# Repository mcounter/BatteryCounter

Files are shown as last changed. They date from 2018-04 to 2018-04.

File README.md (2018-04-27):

# **Battery Counter**

A fully autonomous counter of visitors - **MCounter attom**.

This small device can work approximately 1 year with just 2 *LiSOCl2* AA batteries. And it can be assembled manually in small lab without expensive equipment and components used. All parts of this device was designed by me. Main purpose why I share this project - it's demonstration of my skills (part of my portfolio). Fill free use it under [GNU GPL v3](./LICENSE) license terms.

I have no much time to provide good documentation for this projects. But I believe it's well-structured even for people with minimal experience in Embedded Devices. PCB layouts includes mechanical layers which can be visualized in 3D to easy understand location of all components and it physical sizes.

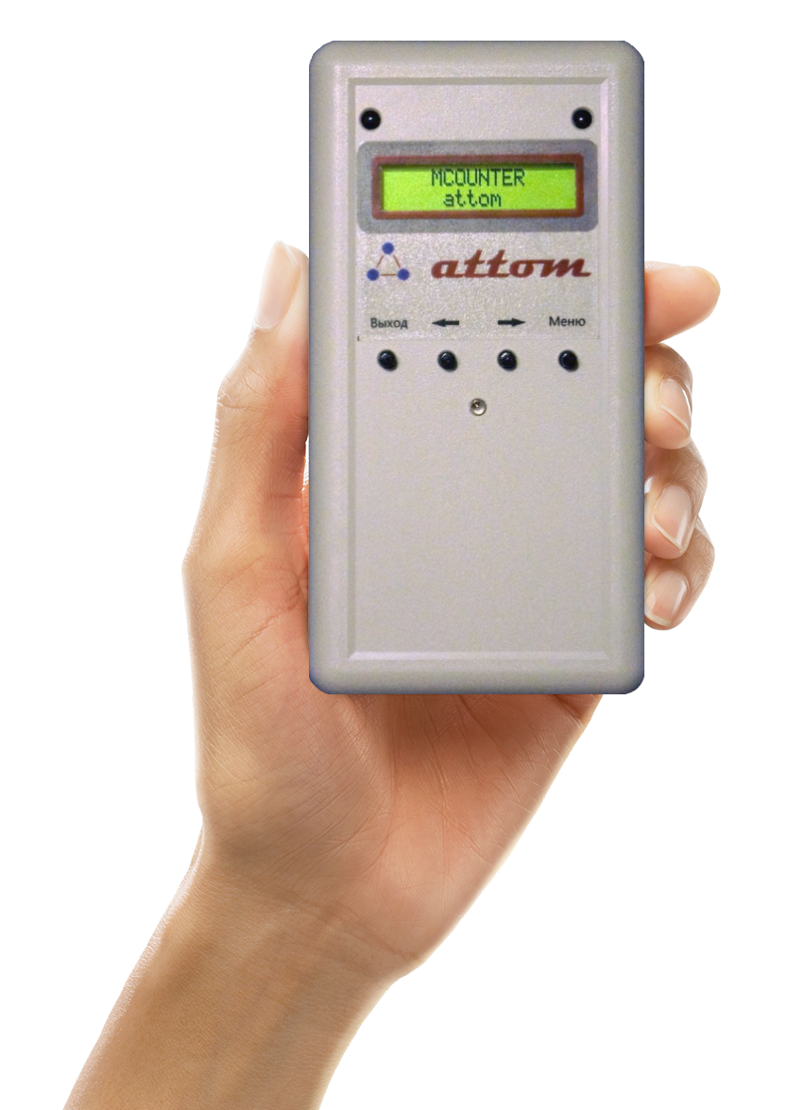
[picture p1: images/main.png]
Battery Counter


*The photo of the real prototype of the device receiver, manually assembled by me. Hand on the background is not mine :)*

**Brief description**

The device is used for automatic counting of people in shopping centers. It consists of 2 parts: Transmitter and Receiver. Device contains small LED digital display with backlight and keyboard with 4 keys. Principle of work: IR (infra-red) rays emitted by Transmitter can be interrupted by passed human. These short termination of IR rays are detected by Receiver and recorded in internal memory, aggregated by hours, days, weeks, months and displayed in the form of different reports on the small device display. Device has good system of noise suppression and can work in different environments and under different conditions.

* Hardware part is designed in the Altium Designer 14.3.10 - [www.altium.com](https://www.altium.com/)
* Software part is designed in the IAR Embedded Workbench for AVR V6.12.1 - [www.iar.com](https://www.iar.com/)
* Menu Builder was designed on C# .NET in VS 2012.
* Receiver microcontroller - **Atmega328P**
* Transmitter microcontroller - **Atmega48PA**
* User documentation (in Russian) - [mcounter_attom_user_guide.pdf](https://mcounter.com.ua/filesdocs/mcounterx/mcounter_attom_user_guide.pdf)

**Project content**
* [micro](./micro) - folder with source code for device Receiver and Transmitter parts.
* [micro/BattRX](./micro/BattRX) - Receiver project.
* [micro/BattTX](./micro/BattTX) - Transmitter project.
* [schemas](./schemas) - folder with component library, board rules and PCB layouts designed in Altium Designer.
* [schemas/Common/Rules](./schemas/Common/Rules) - board rules for Altium Designer.
* [schemas/Common/Library](./schemas/Common/Library) - component library for Altium Designer.
* [schemas/BatteryCounter](./schemas/BatteryCounter) - PCB layouts for Receiver and Transmitter parts.
* [other/LCDMenuBuilder](./other/LCDMenuBuilder) - menu builder - C# .NET program to design and build device menu, use it to translate menu. Program converts menu in set of UserInterface* header and cpp files. Specify target path to [micro/BattRX](./micro/BattRX) and files will be automatically added in the project.
* [LICENSE](./LICENSE) - GNU GENERAL PUBLIC LICENSE v3.

*Thank you for your interest!*

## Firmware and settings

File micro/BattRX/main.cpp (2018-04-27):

#ifndef _MAIN_CPP_
#define _MAIN_CPP_

#include "GlobalSpace.h"
#include "DeviceManager.h"

void Initialization()
{
  __disable_interrupt();

  //Swith off analog comparator
  ACSR=(1<<ACD);  //Analog Comparator: Off

  //__watchdog_reset();
  //WDTCSR = (1<<WDCE) | (1<<WDE);
  //WDTCSR = (1<<WDP3) | (1<<WDE);

  //Enable pullup on all ports

  DDRB = 0x00;
  PORTB = 0xFF ^ ((1<<MEM_SS_BIT) | (1<<SPI_MOSI_BIT) | (1<<SPI_MISO_BIT) | (1<<SPI_SCK_BIT) | (1<<LCD_BACKLIGHT_BIT));
  DDRB = ((1<<MEM_SS_BIT) | (1<<SPI_MOSI_BIT) | (1<<SPI_MISO_BIT) | (1<<SPI_SCK_BIT) | (1<<LCD_BACKLIGHT_BIT));

  DDRC = 0x00;
  PORTC = 0xFF ^ ((1<<LCD_VDD_BIT) | (1<<INDICATOR_LED_BIT) | (1<<LCD_SDA_BIT) | (1<<LCD_SCL_BIT) | (1<<PHOTO1_VDD_BIT) | (1<<PHOTO2_VDD_BIT));
  DDRC = ((1<<LCD_VDD_BIT) | (1<<INDICATOR_LED_BIT) | (1<<LCD_SDA_BIT) | (1<<LCD_SCL_BIT) | (1<<PHOTO1_VDD_BIT) | (1<<PHOTO2_VDD_BIT));

  DDRD = 0x00;
  PORTD = 0xFF ^ ((1<<PHOTO1_IN_BIT) | (1<<PHOTO2_IN_BIT));
  DDRD = ((1<<PHOTO1_IN_BIT) | (1<<PHOTO2_IN_BIT));

  //Disable all external interrupts
  EIMSK = 0x00;

  //Disable all timer interrupts
  TIMSK0 = 0x00;
  TIMSK1 = 0x00;
  TIMSK2 = 0x00;

  //Disable unused modules
  PRR = (1<<PRTWI) | /*(1<<PRTIM0) |*/ (1<<PRTIM1) |                    //Disable TWI, Timer0, Timer1,
        /*(1<<PRTIM2) |*/ (1<<PRSPI) | (1<<PRUSART0) | (1<<PRADC);  //Timer2, SPI, USART0, ADC

  SMCR = 0x00; //Sleep Mode = Idle

  DeviceManager::init();

  __enable_interrupt();
}

int main()
{
  Initialization();

  DeviceManager::run();
}

#endif

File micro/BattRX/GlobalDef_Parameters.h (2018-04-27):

#ifndef __GLOBALDEF_PARAMETERS_H_
#define __GLOBALDEF_PARAMETERS_H_

#define clockFrequency                    (128000)
#define timerDiscreteness                 (5)
#define TWIClockFrequency                 (2560)

#define EXT_MEMORY_SIZE_HOUR_SEGMENT      (12288)
#define EXT_MEMORY_SIZE_DAY_SEGMENT       (3584)
#define EXT_MEMORY_SIZE_MONTH_SEGMENT     (512)
#define EXT_MEMORY_SIZE_TOTAL             (16384)
#define EXT_MEMORY_SEGMENTSIZE            (16)

#if (EXT_MEMORY_SIZE_HOUR_SEGMENT+EXT_MEMORY_SIZE_DAY_SEGMENT+EXT_MEMORY_SIZE_MONTH_SEGMENT > EXT_MEMORY_SIZE_TOTAL)
#error Incorrect memory size
#endif

#define COMMBUFFERSIZE_TWI_MASTER         (64)
#define COMMBUFFERSIZE_SPI_MASTER         (32)

#define LCD_DISPLAY_HEIGHT                (2)
#define LCD_DISPLAY_WIDTH                 (16)

#define DEVICE_PASSWORD_LENGTH            (8)
#define COUNTER_BODY_DETECTION_ADD_MS     (30)

#define BATTERY_CONFIGURATION_LI          (0)
#define BATTERY_CONFIGURATION_STD         (1)

#define BATTERY_CONFIGURATION_SELECTED    (BATTERY_CONFIGURATION_LI)

#endif

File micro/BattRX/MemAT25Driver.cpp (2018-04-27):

#ifndef __MEMAT25DRIVER_CPP_
#define __MEMAT25DRIVER_CPP_

#include <string.h>
#include "MemAT25Driver.h"
#include "CommProtocol_SPI_Master.h"
#include "MultyThreading.h"
#include "CommonFunctions.h"
#include "CRC8.h"

#define MEMAT25_VALPERSEGMENT_HOUR    (3)
#define MEMAT25_VALPERSEGMENT_DAY     (2)
#define MEMAT25_VALPERSEGMENT_MONTH   (2)

#define MEMAT25_ERRORIDLETIME   (3000)
#define MEMAT25_BLOCKTIME       (30000)

#define MEMAT25CMD_WREN         (0x06)
#define MEMAT25CMD_WRDI         (0x04)
#define MEMAT25CMD_RDSR         (0x05)
#define MEMAT25CMD_WRSR         (0x01)
#define MEMAT25CMD_READ         (0x03)
#define MEMAT25CMD_WRITE        (0x02)

#define MEMAT25STATUS_NORMAL    (0x02)
#define MEMAT25STATUS_FLG_BUSY  (0x01)

using namespace Functions::Common;

namespace MemAT25Driver
{
  typedef enum
  {
    MemAT25ResourceStatus_Disabled = 0x00,
    MemAT25ResourceStatus_Ready = 0x01,
    MemAT25ResourceStatus_Scheduled = 0x02,
    MemAT25ResourceStatus_InProcess = 0x03,
    MemAT25ResourceStatus_Blocked = 0x04,
  } TMemAT25ResourceStatus;

  typedef enum
  {
    MemAT25ProtocolStatus_WriteStatusRegWREN = 0,
    MemAT25ProtocolStatus_WriteStatusReg = 1,
    MemAT25ProtocolStatus_WriteDataWREN = 2,
    MemAT25ProtocolStatus_WriteData = 3,
    MemAT25ProtocolStatus_ReadData = 4,
    MemAT25ProtocolStatus_ParseData = 5,
    MemAT25ProtocolStatus_ReadDataValidate = 6,
    MemAT25ProtocolStatus_ValidateData = 7,
  } TMemAT25ProtocolStatus;

  typedef enum
  {
    MemAT25WaitingStatus_None = 0,
    MemAT25WaitingStatus_Schedule = 1,
    MemAT25WaitingStatus_Wait = 2,
  } TMemAT25WaitingStatus;

  typedef struct
  {
    unsigned char data[12];

    unsigned long periodNum:24;
    unsigned long crc8:8;
  } TMem25DataSegmentStd;

  typedef struct
  {
    unsigned long InCnt1:13;
    unsigned long OutCnt1:13;
    unsigned long NoSensorMin1:6;

    unsigned long InCnt2:13;
    unsigned long OutCnt2:13;
    unsigned long NoSensorMin2:6;

    unsigned long InCnt3:13;
    unsigned long OutCnt3:13;
    unsigned long NoSensorMin3:6;

  } TMem25DataSegmentHour;

  typedef struct
  {
    unsigned short InCnt1;
    unsigned short OutCnt1;
    unsigned short NoSensorMin1;

    unsigned short InCnt2;
    unsigned short OutCnt2;
    unsigned short NoSensorMin2;
  } TMem25DataSegmentDay;

  typedef struct
  {
    unsigned char InCnt1H;
    unsigned short InCnt1L;
    unsigned char OutCnt1H;
    unsigned short OutCnt1L;

    unsigned char InCnt2H;
    unsigned short InCnt2L;
    unsigned char OutCnt2H;
    unsigned short OutCnt2L;
  } TMem25DataSegmentMonth;

  TMemAT25Operation operation;
  TMemAT25DataSegment dataSegment;

  TMem25DataSegmentStd operationBuffer;
  GLOBAL::Counter::TCounterPeriodData counterValue;
  TMemAT25COperationResult operationResult;

  TMemAT25ResourceStatus resourceStatus = MemAT25ResourceStatus_Disabled;
  unsigned char protocolStatus;
  TMemAT25WaitingStatus waitingStatus;

  __monitor void enable()
  {
    CommProtocol_SPI_Master::enable();

    resourceStatus = MemAT25ResourceStatus_Ready;
  }

  __monitor void disable()
  {
    MEM_SS_DIR = 1;
    MEM_SS_PORT = 1;

    CommProtocol_SPI_Master::disable();

    resourceStatus = MemAT25ResourceStatus_Disabled;
  }

  bool enabled()
  {
    return resourceStatus != MemAT25ResourceStatus_Disabled;
  }

  bool ready()
  {
    return resourceStatus == MemAT25ResourceStatus_Ready;
  }

  __monitor void init()
  {
    disable();
  }

  void schedule()
  {
    resourceStatus = MemAT25ResourceStatus_Scheduled;
  }

  void finish()
  {
    resourceStatus = MemAT25ResourceStatus_Ready;
  }

  void inProcess()
  {
    GLOBAL::MultyThreading::setTimer(GLOBALTIMERS_MEMAT25_ERRORTIMER, MEMAT25_ERRORIDLETIME);
    resourceStatus = MemAT25ResourceStatus_InProcess;
  }

  bool startMemOperation(TMemAT25Operation _operation, TMemAT25DataSegment _dataSegment)
  {
    if (!ready())
    {
      return false;
    }

    operation = _operation;
    dataSegment = _dataSegment;
    operationResult = MemAT25COperationResult_None;
    waitingStatus = MemAT25WaitingStatus_None;

    schedule();

    return true;
  }

  void scheduleCmd(unsigned char _cmd, unsigned char _parmLng)
  {
    CommProtocol_SPI_Master::bufferSPI.length = _parmLng + 1;
    CommProtocol_SPI_Master::bufferSPI.status = CommProtocol_SPI_Master::SPIBufferStatus_Ready;
    CommProtocol_SPI_Master::bufferSPI.result = CommProtocol_SPI_Master::SPIResultCodeType_OK;
    CommProtocol_SPI_Master::bufferSPI.buffer[0] = _cmd;

    memset(CommProtocol_SPI_Master::bufferSPI.buffer + 1, 0xFF, _parmLng);
  }

  void scheduleCmdWREN()
  {
    scheduleCmd(MEMAT25CMD_WREN, 0);
  }

  void scheduleCmdRDSR()
  {
    waitingStatus = MemAT25WaitingStatus_Wait;
    scheduleCmd(MEMAT25CMD_RDSR, 1);
  }

  void scheduleCmdWRSR()
  {
    waitingStatus = MemAT25WaitingStatus_Wait;
    scheduleCmd(MEMAT25CMD_WRSR, 1);
    CommProtocol_SPI_Master::bufferSPI.buffer[1] = MEMAT25STATUS_NORMAL;
  }

  void setMemAddr()
  {
    unsigned short memAddr;

    switch (dataSegment)
    {
      case MemAT25DataSegment_Hour:
        memAddr = ((counterValue.periodNumHour / MEMAT25_VALPERSEGMENT_HOUR) % (EXT_MEMORY_SIZE_HOUR_SEGMENT / EXT_MEMORY_SEGMENTSIZE)) * EXT_MEMORY_SEGMENTSIZE;
        break;

      case MemAT25DataSegment_Day:
        memAddr = (((counterValue.periodNumDay / MEMAT25_VALPERSEGMENT_DAY) % (EXT_MEMORY_SIZE_DAY_SEGMENT / EXT_MEMORY_SEGMENTSIZE)) * EXT_MEMORY_SEGMENTSIZE) + EXT_MEMORY_SIZE_HOUR_SEGMENT;
        break;

      case MemAT25DataSegment_Month:
        memAddr = (((counterValue.periodNumMonth / MEMAT25_VALPERSEGMENT_MONTH) % (EXT_MEMORY_SIZE_MONTH_SEGMENT / EXT_MEMORY_SEGMENTSIZE)) * EXT_MEMORY_SEGMENTSIZE) + EXT_MEMORY_SIZE_HOUR_SEGMENT + EXT_MEMORY_SIZE_DAY_SEGMENT;
        break;
    }

    CommProtocol_SPI_Master::bufferSPI.buffer[1] = (unsigned char)(memAddr >> 8);
    CommProtocol_SPI_Master::bufferSPI.buffer[2] = (unsigned char)memAddr;
  }

  void scheduleCmdRead()
  {
    scheduleCmd(MEMAT25CMD_READ, 2 + EXT_MEMORY_SEGMENTSIZE);
    setMemAddr();
  }

  void maskOperationBuffer()
  {
    unsigned char* operationBufferPtr = (unsigned char*)(&operationBuffer);

    for (unsigned char i = 0; i < sizeof(TMem25DataSegmentStd); i++)
    {
      operationBufferPtr[i] ^= GLOBAL::DeviceProfile::MemorySecureTemplate[i];
    }
  }

  void scheduleCmdWriteHour()
  {
    TMem25DataSegmentHour* curDataSegment = (TMem25DataSegmentHour*)(operationBuffer.data);

    unsigned char subPeriodNum = counterValue.periodNumHour % MEMAT25_VALPERSEGMENT_HOUR;
    operationBuffer.periodNum = (counterValue.periodNumHour / MEMAT25_VALPERSEGMENT_HOUR) * MEMAT25_VALPERSEGMENT_HOUR;
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

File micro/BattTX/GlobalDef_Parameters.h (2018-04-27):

#ifndef __GLOBALDEF_PARAMETERS_H_
#define __GLOBALDEF_PARAMETERS_H_

#define clockFrequency                    (128000)
#define timerDiscreteness                 (4)

#define NODETECTION_PRESCALER_LEVEL       (3)

#if (((((clockFrequency/8) * timerDiscreteness * NODETECTION_PRESCALER_LEVEL)/1000) - 1) > 255)
#error Incorrect timer configuration
#endif

#define BATTERY_CONFIGURATION_LI          (0)
#define BATTERY_CONFIGURATION_STD         (1)

#define BATTERY_CONFIGURATION_SELECTED    (BATTERY_CONFIGURATION_LI)

#endif
